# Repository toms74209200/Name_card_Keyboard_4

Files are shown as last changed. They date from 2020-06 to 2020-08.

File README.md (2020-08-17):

# Study 4 Scarlet

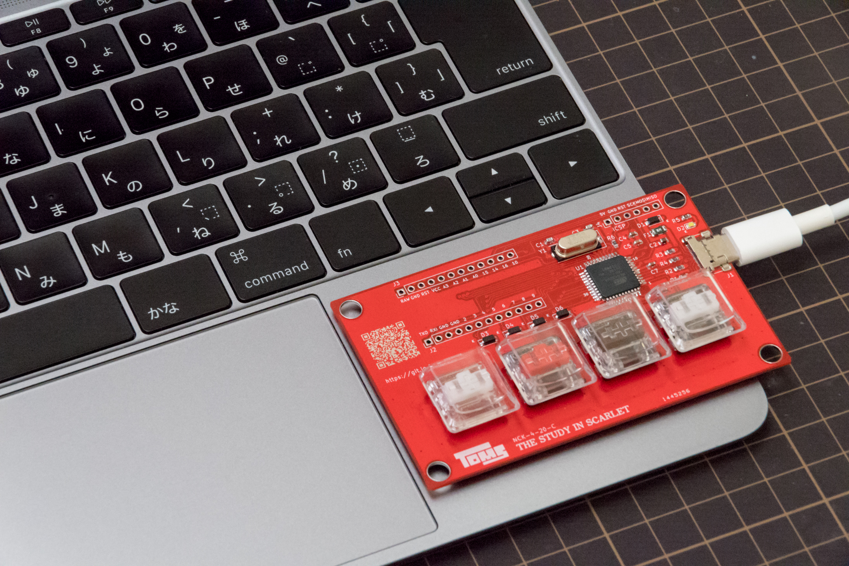
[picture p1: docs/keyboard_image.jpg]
Keyboard


- 4 Keyboard
- Kailh Choc type
- Business card size(91mm x 55mm)
- arduino(Pro micro) compatible
- USB type-C interface

## Usage

See [User guide (English)](./docs/user_guide_en.md) ([日本語](./docs/user_guide_ja.md)). 

## License

MIT License

## Author

[toms74209200](<https://github.com/toms74209200>)

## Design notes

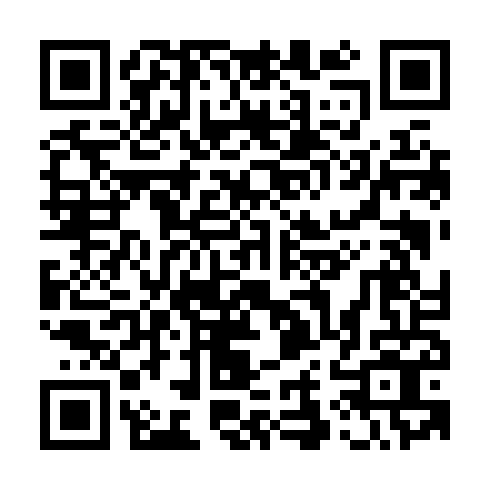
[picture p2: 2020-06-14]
pcb/qr20200614220923643.png

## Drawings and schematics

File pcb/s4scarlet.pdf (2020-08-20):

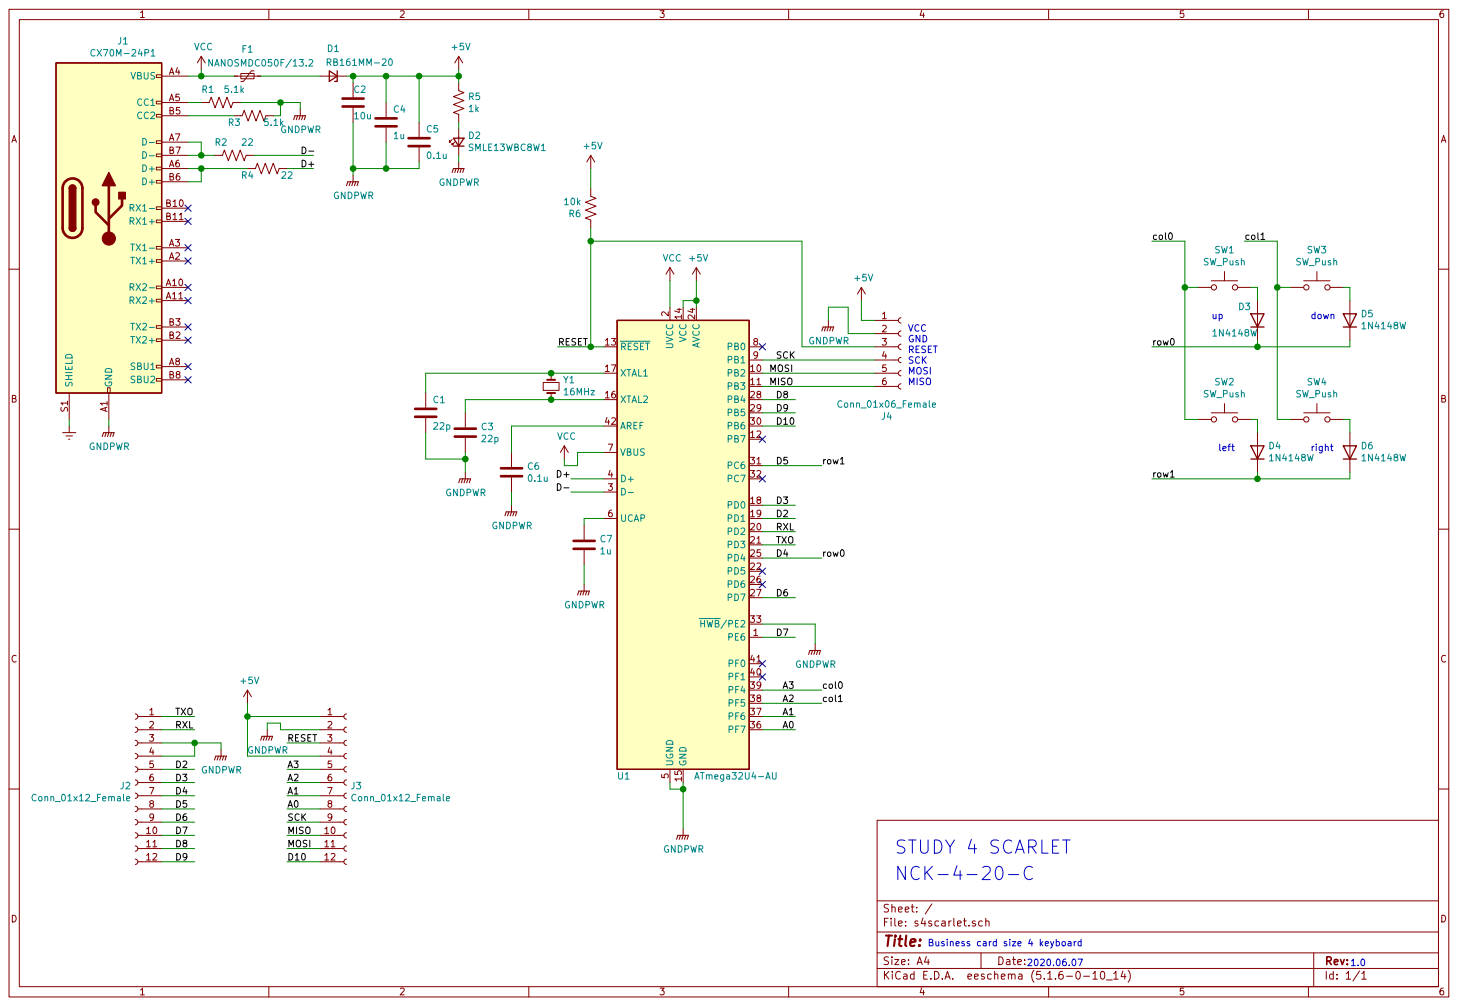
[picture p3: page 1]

2 PD2 20 PD3 21 PD5 22 AVCC 24 PD4 25 PD6 26 PD7 27 PB4 28 PB5 29 D- 3 PB6 30 PC6 31 PC7 32 HWB/PE2 33 PF7 36 PF6 37 PF5 38 PF4 39 D+ 4 PF1 40 PF0 41 AREF 42 UGND

left Business card size 4 keyboard

Id: 1/1 Title: File: s4scarlet.sch Sheet: /

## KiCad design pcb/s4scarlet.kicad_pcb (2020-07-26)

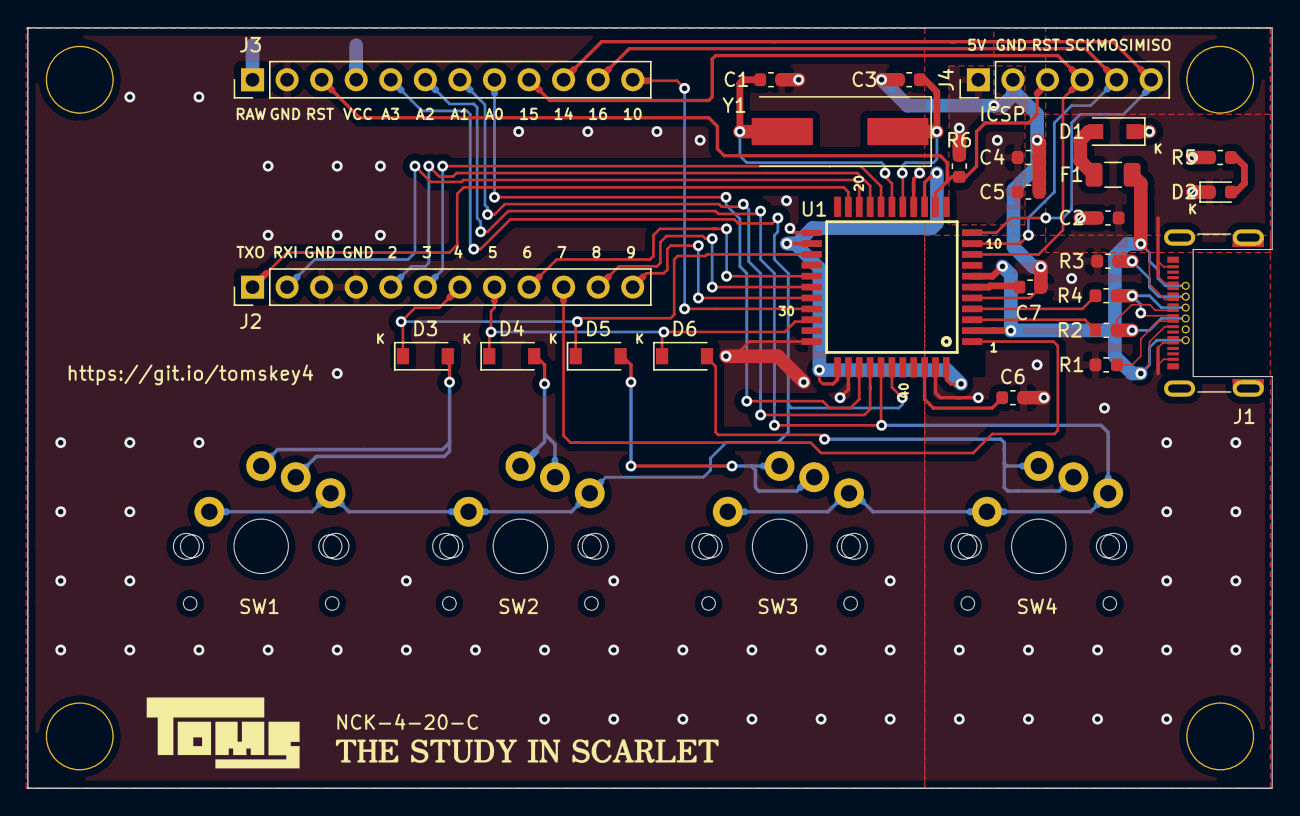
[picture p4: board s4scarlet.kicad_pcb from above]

Board: 2 copper layers, 91.4 x 55.9 mm, 34 parts (0 on the bottom side), 38 nets.

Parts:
C1, C3: 22p; C_0603_1608Metric
C2: 10u; C_0603_1608Metric
C4, C7: 1u; C_0603_1608Metric
C5, C6: 0.1u; C_0603_1608Metric
D1: RB161MM-20; D_SOD-123F
D2: SMLE13WBC8W1; LED_0603_1608Metric
D3, D4, D5, D6: 1N4148W; D_SOD-123
F1: NANOSMDC050F/13.2; Fuse_1206_3216Metric
J1: CX70M-24P1; USB-C_Female_CX70M-24P1
J2, J3: Conn_01x12_Female; PinHeader_1x12_P2.54mm_Vertical
J4: Conn_01x06_Female; PinHeader_1x06_P2.54mm_Vertical
R1, R2, R3, R4: 22; R_0603_1608Metric
R5: 1k; R_0603_1608Metric
R6: 10k; R_0603_1608Metric
Ref**: Val**; HOLE
Ref**#2, Ref**#3, Ref**#4: Val**; HOLE
SW1, SW2, SW3, SW4: SW_Push; CherryMX_Choc_1u
U1: ATmega32U4-AU; ATMEGA32U4-AU
Y1: 16MHz; Crystal_SMD_HC49-SD

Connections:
+5V: C2.1, C4.1, C5.1, D1.1, J3.1, J3.4, J4.1, R5.1, R6.2, U1.14, U1.24, U1.34, U1.44
/A0: J3.8, U1.36
/A1: J3.7, U1.37
/A2: J3.6, SW3.1, SW4.1, U1.38
/A3: J3.5, SW1.1, SW2.1, U1.39
/D2: J2.5, U1.19
/D3: J2.6, U1.18
/D4: D3.1, D5.1, J2.7, U1.25
/D5: D4.1, D6.1, J2.8, U1.31
/D6: J2.9, U1.27
/D7: J2.10, U1.1
/D8: J2.11, U1.28
/D9: J2.12, U1.29
/D10: J3.12, U1.30
/D+: R4.1, U1.4
/D-: R2.1, U1.3
/MISO: J3.10, J4.6, U1.11
/MOSI: J3.11, J4.5, U1.10
/RESET: J3.3, J4.3, R6.1, U1.13
/RXL: J2.2, U1.20
/SCK: J3.9, J4.4, U1.9
/TXO: J2.1, U1.21
GNDPWR: C1.2, C2.2, C3.2, C4.2, C5.2, C6.2, C7.2, D2.1, J1.A1, J1.A12, J1.B1, J1.B12, J2.3, J2.4, J3.2, J4.2, R1.1, R3.1, U1.5, U1.15, U1.23, U1.33, U1.35, U1.43
unnamed: C1.1, U1.17, Y1.2
unnamed: C3.1, U1.16, Y1.1
unnamed: C6.1, U1.42
unnamed: C7.1, U1.6
unnamed: D1.2, F1.1
unnamed: D2.2, R5.2
unnamed: D3.2, SW1.2
unnamed: D4.2, SW2.2
unnamed: D5.2, SW3.2
unnamed: D6.2, SW4.2
unnamed: J1.A5, R1.2
unnamed: J1.A6, J1.B6, R4.2
unnamed: J1.A7, J1.B7, R2.2
unnamed: J1.B5, R3.2
VCC: F1.2, J1.A4, J1.A9, J1.B4, J1.B9, U1.2, U1.7

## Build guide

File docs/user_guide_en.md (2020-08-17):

# User guide

## Overview

overview

1. 4 Keybord
2. USB type-C connector
3. Arduino (Pro micro) compatible thrue holes
4. ICSP interface

## USB type-C

The board has a USB type-C connector as a interface. But it does not work with type-C to type-C cable. You must use type-C to type-A cable.

## Use for Keyboard

The board has programed keyboard firmware(QMK firmware). The keymap are allocated in order of `Cmd`-`z`, `Cmd`-`x`, `Cmd`-`c`, `Cmd`-`v` from the left.

### development environment

To change the keymap, it is necessary to build the development environment. For details, see the following.

[Setting Up Your QMK Environment - Setup - QMK](https://beta.docs.qmk.fm/tutorial/newbs_getting_started#setting-up-your-qmk-environment)

### To change keymap

Changing the keymap needs [the repository of QMK firmware](https://github.com/qmk/qmk_firmware). Do git clone the repository.

```bash
$ git clone git@github.com:qmk/qmk_firmware.git
```

Run `./util/qmk_install.sh`, `make git-submodule` if you need to build it.

The source codes for the keyboard's firmware can be found in [`./firmware/s4scarlet/`](../firmware/s4scarlet). Please put the source codes  under `keyboards/` in the QMK firmware repository.

```bash
s4scarlet$ mv ./firmware/s4scarlet/ /qmk_firmware/keyboards/
```

The keymap for the keyboard are located under [`./firmware/s4scarlet/keymap/`](../firmware/s4scarlet/keymap). To edit the `defualt` keymap, you can edit `keymap.c`. (Not recommended). To prepare new keymap and edit it, use the following command.

```bash
qmk_firmware$ ./util/new_keymap.sh s4scarlet <keymap_name>
```

If you prepare new keymap, a directory: `./firmware/s4scarlet/keymap/<keymap_name>` will be created. You can edit `keymap.c` that is in this directory to edit the keymap.

You use the `make` command as to build the firmware.

```bash
qmk_firmware$ make s4scarlet:<keymap_name>
```

Programing the firmware also uses the `make` command.

```bash
qmk_firmware$ make s4scarlet:<keymap_name>:avrdude
```

When you execute the above, a termnal displays "Detecting USB port, reset your controller now...'' as below. At this time, reset the board by shorting the ground pin and the reset pin on the board.

```bash
qmk_firmware$ make s4scarlet:<keymap_name>:avrdude
QMK Firmware 0.9.50
Making s4scarlet with keymap default and target avrdude
~
 * The firmware size is fine - 15018/28672 (52%, 13654 bytes free)
Detecting USB port, reset your controller now...
```

At this time, it may stop working (often), so in that case, you terminate command (`Ctrl`-`c`) and try again.

### More details

For more details, please refer to the official QMK firmware documentation.

[Quantum Mechanical Keyboard Firmware](https://docs.qmk.fm/#/?id=quantum-mechanical-keyboard-firmware)

## Use for Arduino(Pro micro)

The Arduino boot loader is programed in the board, so it can be used as it is as an Arduino(Pro micro). Please refer to the [Schematic](#sch) section.

## Schematic

See [s4scarlet.pdf](../pcb/s4scarlet.pdf).

### Pin assignment

#### 3. Arduino (Pro micro) compatible thrue holes

This thrue holes are compatible sparkfun's Pro micro pins. Refer to the link below for details

- [sparkfun Pro micro product page](https://www.sparkfun.com/products/12640)
    https://www.sparkfun.com/products/12640
- [sparkfun Pro micro Graphical Datasheet](https://cdn.sparkfun.com/assets/f/d/8/0/d/ProMicro16MHzv2.pdf)
    https://cdn.sparkfun.com/assets/f/d/8/0/d/ProMicro16MHzv2.pdf

**CAUTION** pins:`4`, `5`, `A2`, `A3` share with keybord switch signals.

Pro micro compatible pin assign

| Down-side | Up-side |
| --- | --- |
| TXO | RAW |
| RXI | GND |
| GND | RST |
| GND | VCC |
| 2 | A3 |
| 3 | A2 |
| 4 | A1 |
| 5 | A0 |
| 6 | 15 |
| 7 | 14 |
| 8 | 16 |
| 9 | 10 |

#### 4. ICSP interface

ICSP (In-Circuit serial programing) pins are used for programing arduino boot loader.

| pin  | Signal |
| ---- | --- |
| 1 | 5V |
| 2 | GND |
| 3 | RST |
| 4 | SCK |
| 5 | MOSI |
| 6 | MISO |

##

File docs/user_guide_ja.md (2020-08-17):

# ユーザーガイド

## 概要

overview

1. 4キーボード
2. USB type-C コネクタ
3. Arduino (Pro micro) 互換スルーホール
4. ICSP インターフェイス

## USB type-C コネクタ

インターフェースとしてUSB type-C（メス）コネクタがあります. しかしtype-C - type-Cケーブルは対応していません. 必ずtype-C - type-Aケーブルを使用してください.

## キーボードとして使う

装置にはあらかじめキーボードのファームウェア(QMK firmware)が書き込まれています. キーマップは左から`Cmd`-`z`, `Cmd`-`x`, `Cmd`-`c`, `Cmd`-`v` となっています.

### 開発環境

キーマップを変更する場合, 環境の構築が必要になります. 詳細は以下を確認ください.

[Setting Up Your QMK Environment - Setup - QMK](https://beta.docs.qmk.fm/tutorial/newbs_getting_started#setting-up-your-qmk-environment)

### キーマップの変更

キーマップの変更は[QMK firmware のリポジトリ](https://github.com/qmk/qmk_firmware)をクローンして行います.

```bash
$ git clone git@github.com:qmk/qmk_firmware.git
```

必要であれば, `util/qmk_install.sh`, `make git-submodule`  などを実行してビルドできるようにしてください.

このキーボードのファームウェアに関するソースコードは [`./firmware/s4scarlet/`](../firmware/s4scarlet) 以下にあります. これをQMK firmwareのリポジトリの `keyboards/` 以下に設置してください.

```bash
s4scarlet$ mv ./firmware/s4scarlet/ /qmk_firmware/keyboards/
```

このキーボードのキーマップは [`./firmware/s4scarlet/keymaps/`](../firmware/s4scarlet/keymaps) 以下にあります. `defualt` のキーマップを編集する場合は `keymap.c` を編集してください（推奨しません）. キーマップを新たに用意して編集するには以下のコマンドを利用します.

```bash
qmk_firmware$ ./util/new_keymap.sh s4scarlet <keymap_name>
```

新たにキーマップを用意した場合は`./firmware/s4scarlet/keymaps/<keymap_name>` が作成されます. このディレクトリの`keymap.c` を編集してください.

ファームウェアのビルドは `make` コマンドで実行します.

```bash
qmk_firmware$ make s4scarlet:<keymap_name>
```

またファームウェアの書き込みも同様に `make` コマンドを使用します.

```bash
qmk_firmware$ make s4scarlet:<keymap_name>:avrdude
```

上記を実行すると以下のように「Detecting USB port, reset your controller now...」と表示されます. このとき基板上のグラウンドピンとリセットピンを短絡して, 装置をリセットしてください.

```bash
qmk_firmware$ make s4scarlet:<keymap_name>:avrdude
QMK Firmware 0.9.50
Making s4scarlet with keymap default and target avrdude
~
 * The firmware size is fine - 15018/28672 (52%, 13654 bytes free)
Detecting USB port, reset your controller now...
```

このときそのままそのまま動かなくなることが（多々）あるため, その場合は中断(`Ctrl`-`c`)して再度やり直してください.

### 参考

その他の詳細についてはQMK firmwareの公式ドキュメントを参考にしてください.

[Quantum Mechanical Keyboard Firmware](https://docs.qmk.fm/#/?id=quantum-mechanical-keyboard-firmware)

以下のリンクでもQMK firmwareの操作について解説されています.

- [QMK チートシート - Qiita](https://qiita.com/rai_suta/items/0376ed4ce6498bb85770)
- [はじめてのQMKキーマップ編集 - Qiita](https://qiita.com/marksard/items/9317949ce1da327f7436)

また類似のキーボードとして以下のビルドガイドが参考になります.

- [meishi2 keyboard ビルドガイド - たのしい人生](https://biacco42.hatenablog.com/entry/2019/08/10/185624)

## Arduino (Pro micro) として使う

装置にはあらかじめArduinoのブートローダーが書き込まれています. そのためそのままArduino(Pro micro) として使用することができます. [回路図](#sch)の項を参考にしてください.

## 回路図

回路図は [s4scarlet.pdf](../pcb/s4scarlet.pdf) をご覧ください.

### ピン配列

#### 3. Arduino (Pro micro) 互換スルーホール

スルーホールは sparkfun社のPro microのピンと同じ配列です. 詳細は以下のリンクを参照してください.

- [sparkfun Pro micro製品ページ](https://www.sparkfun.com/products/12640)
    https://www.sparkfun.com/products/12640
- [sparkfun Pro micro Graphical Datasheet](https://cdn.sparkfun.com/assets/f/d/8/0/d/ProMicro16MHzv2.pdf)
    https://cdn.sparkfun.com/assets/f/d/8/0/d/ProMicro16MHzv2.pdf

**注意** `4`, `5`, `A2`, `A3` ピンはキーボードスイッチと配線を共有しています.

Pro micro compatible pin assign

| Down-side | Up-side |
| --- | --- |
| TXO | RAW |
| RXI | GND |
| GND | RST |
| GND | VCC |
| 2 | A3 |
| 3 | A2 |
| 4 | A1 |
| 5 | A0 |
| 6 | 15 |
| 7 | 14 |
| 8 | 16 |
| 9 | 10 |

#### 4. ICSP インターフェイス

ICSP (In-Circuit serial programing) はarduinoのブートローダーの書き込みに使用します.

| pin  | Signal |
| ---- | --- |
| 1 | 5V |
| 2 | GND |
| 3 | RST |
| 4 | SCK |
| 5 | MOSI |
| 6 | MISO |

##

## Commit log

2020-06-14 [add]add first, PCB
    [name_card_keyboard.kicad_pcb, name_card_keyboard.sch]
2020-06-18 [change]change AW
    [name_card_keyboard.kicad_pcb]
2020-06-18 [add]add gerber
    [name_card_keyboard-B_Cu.gbr, name_card_keyboard-B_Mask.gbr, name_card_keyboard-B_SilkS.gbr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]
2020-06-22 [add]add drill gerber data
    [name_card_keyboard-NPTH.drl, name_card_keyboard-PTH.drl]
2020-07-02 [change]conmine drillgerber data
    [name_card_keyboard-NPTH.drl, name_card_keyboard.drl]
2020-07-04 [add]add pin assign
2020-07-19 [fix]fix USB data signal
    [name_card_keyboard.sch]
2020-07-26 [change]update pcb
    [name_card_keyboard.kicad_pcb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]
2020-08-20 [fix]change PD value of USB CC pins
    [s4scarlet.sch]
